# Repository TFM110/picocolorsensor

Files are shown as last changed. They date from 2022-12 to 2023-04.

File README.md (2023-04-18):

# REV Color Sensor Raspberry Pi Pico

This uses a Serial connection to transmit data for 2 Rev Color Sensors to a roboRIO using a Pi Pico.

## Pi Pico Setup

You can follow the raspberry pi instructions to build the executable in the pico folder. Their instructions are complicated for windows, so I have also provided a prebuilt uf2 file to directly upload to the device. To deploy this file this, hold down the button on your devide, and connect to your computer. This will open as a drive. Copy the picocolorsensor.uf2 file in the `pico` folder to the drive. It will automatically reboot and start running the code with no configuration required.

## Hardware connections

By default, the code will connect to 2 color sensors. 

Please solder all the necessary components onto the PCB, files are provided in the `Pico Color Sensor PCB` folder to print/order your own PCB as well as the Bill of Materials(BOM) needed for the PCB.

You may solder both the DuPont and/or the JST connector but you may only use one on both sides.

V2



Differences between V1 and V2:

* Replaced the SMDs with THTs components so teams don’t need to worry about small pieces and allows easier soldering with THTs
* Made the DuPont headers at a right angle to minimize the usage of the vertical space
* Both the Dupont and JST connector face the side
* FIXED: The JST connector on the V1 had the SDA and SCL channels in the wrong pins, V2 has fixed that. This allows you to use a regular 4-pin JST PH cable from the color sensor to the board. NOTE: When plugging the JST connector into the board, the connector must be upside down then how you plug into the color sensor.

V2.1



V2.5



Differences between V2 and V2.1/V2.5

* V2.1 and V2.5 now have 4 layers of traces instead of 2

Differences between V2.1 and V2.5

* V2.5 now has a male MXP port to allow you to use a NavX.
* V2.5 also has extra mounting holes for you to be able to securely mount the NavX
* NOTE: Due to the rule R713 in the 2022 Game Manual, you are not allowed to use any of the pins available on the NavX to control any actuators

## WPILib Setup

Copy the files corresponding to the language you use in the `wpilib` folder into your project. Instantiate a `PicoColorSensor` (java) or `pico::ColorSensor` (C++) object. You can only create 1 instance of this object. You can then use the functions to grab each color sensors value, and if its connected.

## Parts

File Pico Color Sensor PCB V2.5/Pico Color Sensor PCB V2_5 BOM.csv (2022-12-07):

Component Count: | 12
Ref | Qnty | Value | Cmp name | Footprint | Description | Vendor | Price | Total
Pico1, | 1 | Pico | Pico | MCU_RaspberryPi_and_Boards:RPi_Pico_SMD_TH | Raspberry Pi Pico | https://www.raspberrypi.com/products/raspberry-pi-pico/?variant=raspberry-pi-pico | $4.00 | $4.00
DuPont_I2C_1, DuPont_I2C_2, | 2 | Conn_01x04_Male | Conn_01x04_Male | Connector_PinHeader_2.54mm:PinHeader_1x04_P2.54mm_Horizontal | Generic connector, single row, 01x04 | https://www.digikey.com/en/products/detail/adam-tech/PH1RA-04-UA/9830430 | $0.19 | $0.38
JST_I2C_1, JST_I2C_2, | 2 | Conn_01x04_Male | Conn_01x04_Male | Connector_JST:JST_PH_S4B-PH-K_1x04_P2.00mm_Horizontal | Generic connector, single row, 01x04 | https://www.digikey.com/en/products/detail/jst-sales-america-inc/S4B-PH-K-S-LF-SN/926628 |  | $-
MXP1, | 1 | Conn_02x17_Odd_Even | Conn_02x17_Odd_Even | Connector_PinSocket_2.54mm:PinSocket_2x17_P2.54mm_Vertical | Generic connector, double row, 02x17, odd/even pin numbering scheme (row 1 odd numbers, row 2 even numbers) | https://www.digikey.com/en/products/detail/sullins-connector-solutions/SFH11-PBPC-D17-ST-BK/1990092 | $1.81 | $1.81
MXP2, | 1 | Conn_02x17_Odd_Even | Conn_02x17_Odd_Even | Connector_PinHeader_2.54mm:PinHeader_2x17_P2.54mm_Vertical | Generic connector, double row, 02x17, odd/even pin numbering scheme (row 1 odd numbers, row 2 even numbers) | https://www.digikey.com/en/products/detail/sullins-connector-solutions/SBH11-PBPC-D17-ST-BK/1990067 | $0.68 | $0.68
D1, | 1 | D | D | Diode_THT:D_DO-15_P10.16mm_Horizontal | Diode | https://www.digikey.com/en/products/detail/littelfuse-inc/SA5-0A/407714 | $0.43 | $0.43
R1, R2, R3, R4, | 4 | R | R | Resistor_THT:R_Axial_DIN0207_L6.3mm_D2.5mm_P10.16mm_Horizontal | Resistor | https://www.digikey.com/en/products/detail/stackpole-electronics-inc/CF14JT4K70/1741428 | $0.10 | $0.40
 |  |  |  |  |  |  |  | $7.70

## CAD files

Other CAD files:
KiCad-RP-Pico-main/SketchUp Model/Pico.skp

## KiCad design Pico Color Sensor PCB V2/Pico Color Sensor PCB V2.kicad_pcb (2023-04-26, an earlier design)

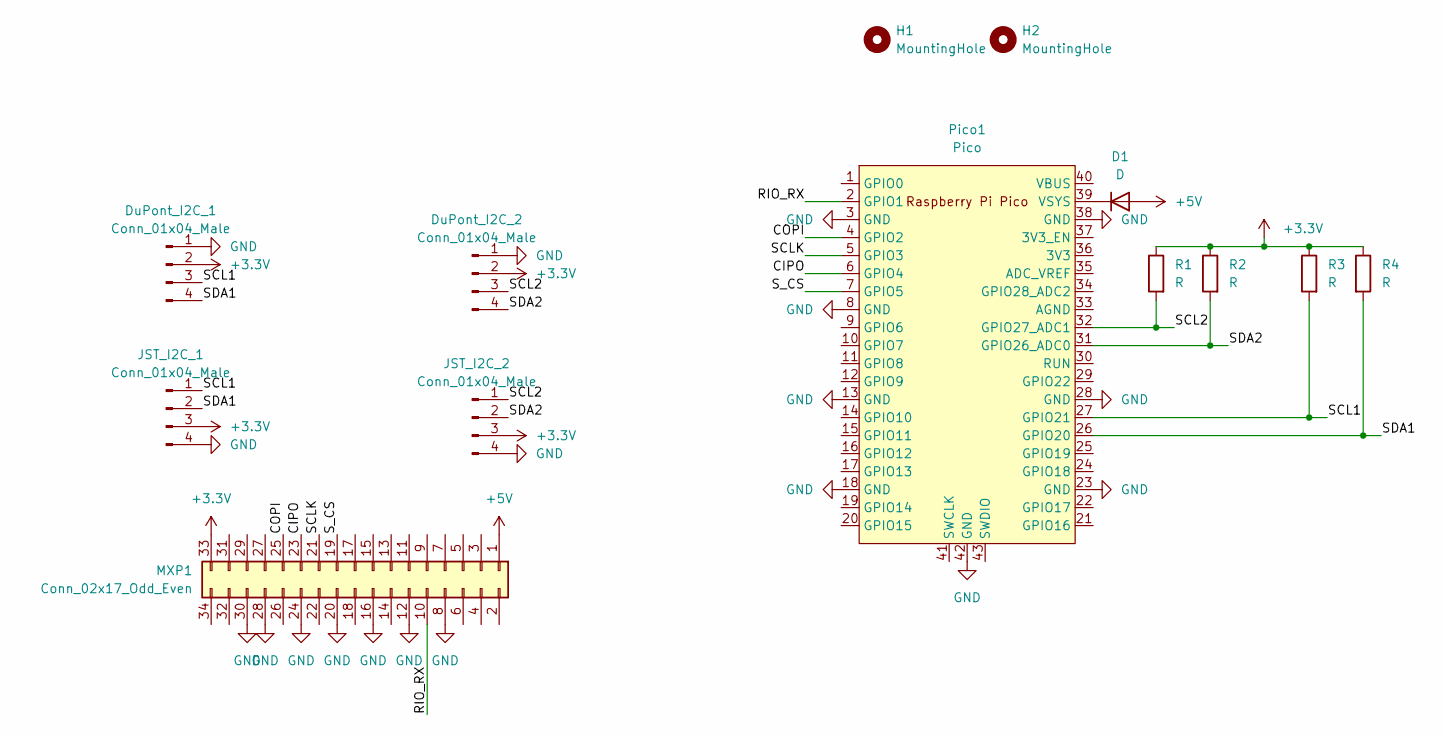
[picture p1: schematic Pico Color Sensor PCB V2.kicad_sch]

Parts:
D1: D; D_DO-15_P12.70mm_Horizontal
DuPont_I2C_1, DuPont_I2C_2: Conn_01x04_Male; PinHeader_1x04_P2.54mm_Horizontal
H1, H2: MountingHole; MountingHole_3.2mm_M3
JST_I2C_1, JST_I2C_2: Conn_01x04_Male; JST_PH_S4B-PH-K_1x04_P2.00mm_Horizontal
MXP1: Conn_02x17_Odd_Even; PinSocket_2x17_P2.54mm_Vertical
Pico1: Pico; RPi_Pico_SMD_TH
R1, R2, R3, R4: R; R_Axial_DIN0207_L6.3mm_D2.5mm_P10.16mm_Horizontal

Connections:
+3.3V: DuPont_I2C_1.2, DuPont_I2C_2.2, JST_I2C_1.3, JST_I2C_2.3, MXP1.33, R1.1, R2.1, R3.1, R4.1
+5V: D1.2 (A), MXP1.1
/CIPO: MXP1.23, Pico1.6 (GPIO4)
/COPI: MXP1.25, Pico1.4 (GPIO2)
/RIO_RX: MXP1.10, Pico1.2 (GPIO1)
/SCL1: DuPont_I2C_1.3, JST_I2C_1.1, Pico1.27 (GPIO21), R3.2
/SCL2: DuPont_I2C_2.3, JST_I2C_2.1, Pico1.32 (GPIO27_ADC1), R1.2
/SCLK: MXP1.21, Pico1.5 (GPIO3)
/SDA1: DuPont_I2C_1.4, JST_I2C_1.2, Pico1.26 (GPIO20), R4.2
/SDA2: DuPont_I2C_2.4, JST_I2C_2.2, Pico1.31 (GPIO26_ADC0), R2.2
/S_CS: MXP1.19, Pico1.7 (GPIO5)
GND: DuPont_I2C_1.1, DuPont_I2C_2.1, JST_I2C_1.4, JST_I2C_2.4, MXP1.8, MXP1.12, MXP1.16, MXP1.20, MXP1.24, MXP1.28, MXP1.30, Pico1.3 (GND), Pico1.8 (GND), Pico1.13 (GND), Pico1.18 (GND), Pico1.23 (GND), Pico1.28 (GND), Pico1.38 (GND), Pico1.42 (GND)
unnamed: D1.1 (K), Pico1.39 (VSYS)

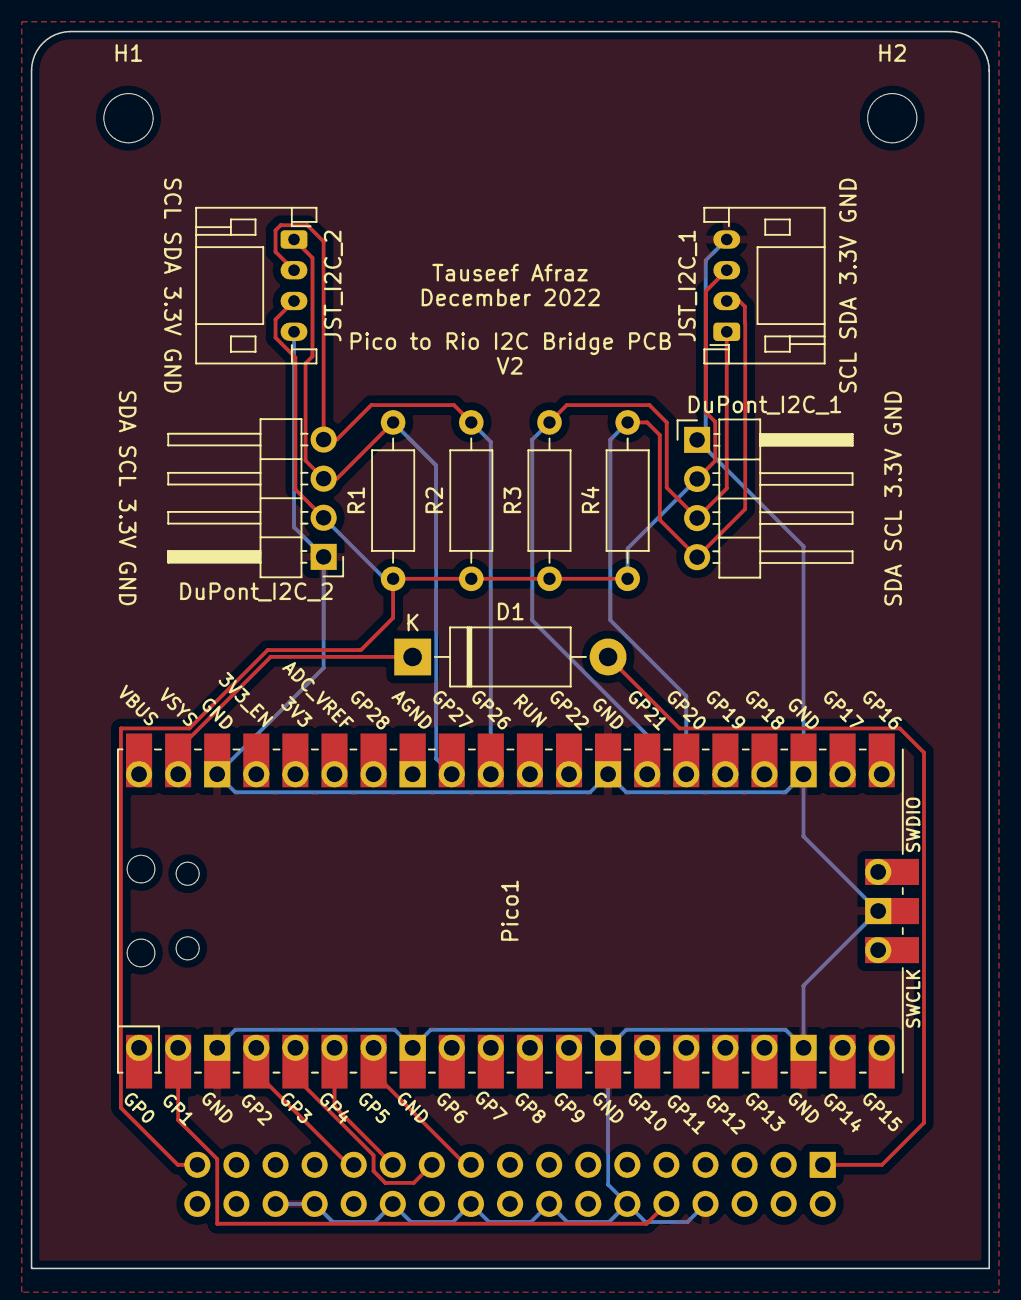
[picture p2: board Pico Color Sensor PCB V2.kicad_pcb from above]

Board: 2 copper layers, 62.2 x 80.4 mm, 13 parts (1 on the bottom side), 13 nets.

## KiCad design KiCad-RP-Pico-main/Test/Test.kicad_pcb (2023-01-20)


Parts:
J1, J2: Conn_01x20; PinSocket_1x20_P1.00mm_Vertical
J3: Conn_01x03; PinSocket_1x03_P1.00mm_Vertical
U1: Pico; RPi_Pico_SMD_TH

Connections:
GND: J1.3, J1.8, J1.13, J1.18, J2.3, J2.13, J2.18, J3.2, U1.3 (GND), U1.8 (GND), U1.13 (GND), U1.18 (GND), U1.23 (GND), U1.28 (GND), U1.38 (GND), U1.42 (GND)
unnamed: J1.1, U1.1 (GPIO0)
unnamed: J1.2, U1.2 (GPIO1)
unnamed: J1.4, U1.4 (GPIO2)
unnamed: J1.5, U1.5 (GPIO3)
unnamed: J1.6, U1.6 (GPIO4)
unnamed: J1.7, U1.7 (GPIO5)
unnamed: J1.9, U1.9 (GPIO6)
unnamed: J1.10, U1.10 (GPIO7)
unnamed: J1.11, U1.11 (GPIO8)
unnamed: J1.12, U1.12 (GPIO9)
unnamed: J1.14, U1.14 (GPIO10)
unnamed: J1.15, U1.15 (GPIO11)
unnamed: J1.16, U1.16 (GPIO12)
unnamed: J1.17, U1.17 (GPIO13)
unnamed: J1.19, U1.19 (GPIO14)
unnamed: J1.20, U1.20 (GPIO15)
unnamed: J2.1, U1.40 (VBUS)
unnamed: J2.2, U1.39 (VSYS)
unnamed: J2.4, U1.37 (3V3_EN)
unnamed: J2.5, U1.36 (3V3)
unnamed: J2.6, U1.35 (ADC_VREF)
unnamed: J2.7, U1.34 (GPIO28_ADC2)
unnamed: J2.8, U1.33 (AGND)
unnamed: J2.9, U1.32 (GPIO27_ADC1)
unnamed: J2.10, U1.31 (GPIO26_ADC0)
unnamed: J2.11, U1.30 (RUN)
unnamed: J2.12, U1.29 (GPIO22)
unnamed: J2.14, U1.27 (GPIO21)
unnamed: J2.15, U1.26 (GPIO20)
unnamed: J2.16, U1.25 (GPIO19)
unnamed: J2.17, U1.24 (GPIO18)
unnamed: J2.19, U1.22 (GPIO17)
unnamed: J2.20, U1.21 (GPIO16)
unnamed: J3.1, U1.43 (SWDIO)
unnamed: J3.3, U1.41 (SWCLK)


Board: 2 copper layers, 43.0 x 65.0 mm, 4 parts (0 on the bottom side), 36 nets.

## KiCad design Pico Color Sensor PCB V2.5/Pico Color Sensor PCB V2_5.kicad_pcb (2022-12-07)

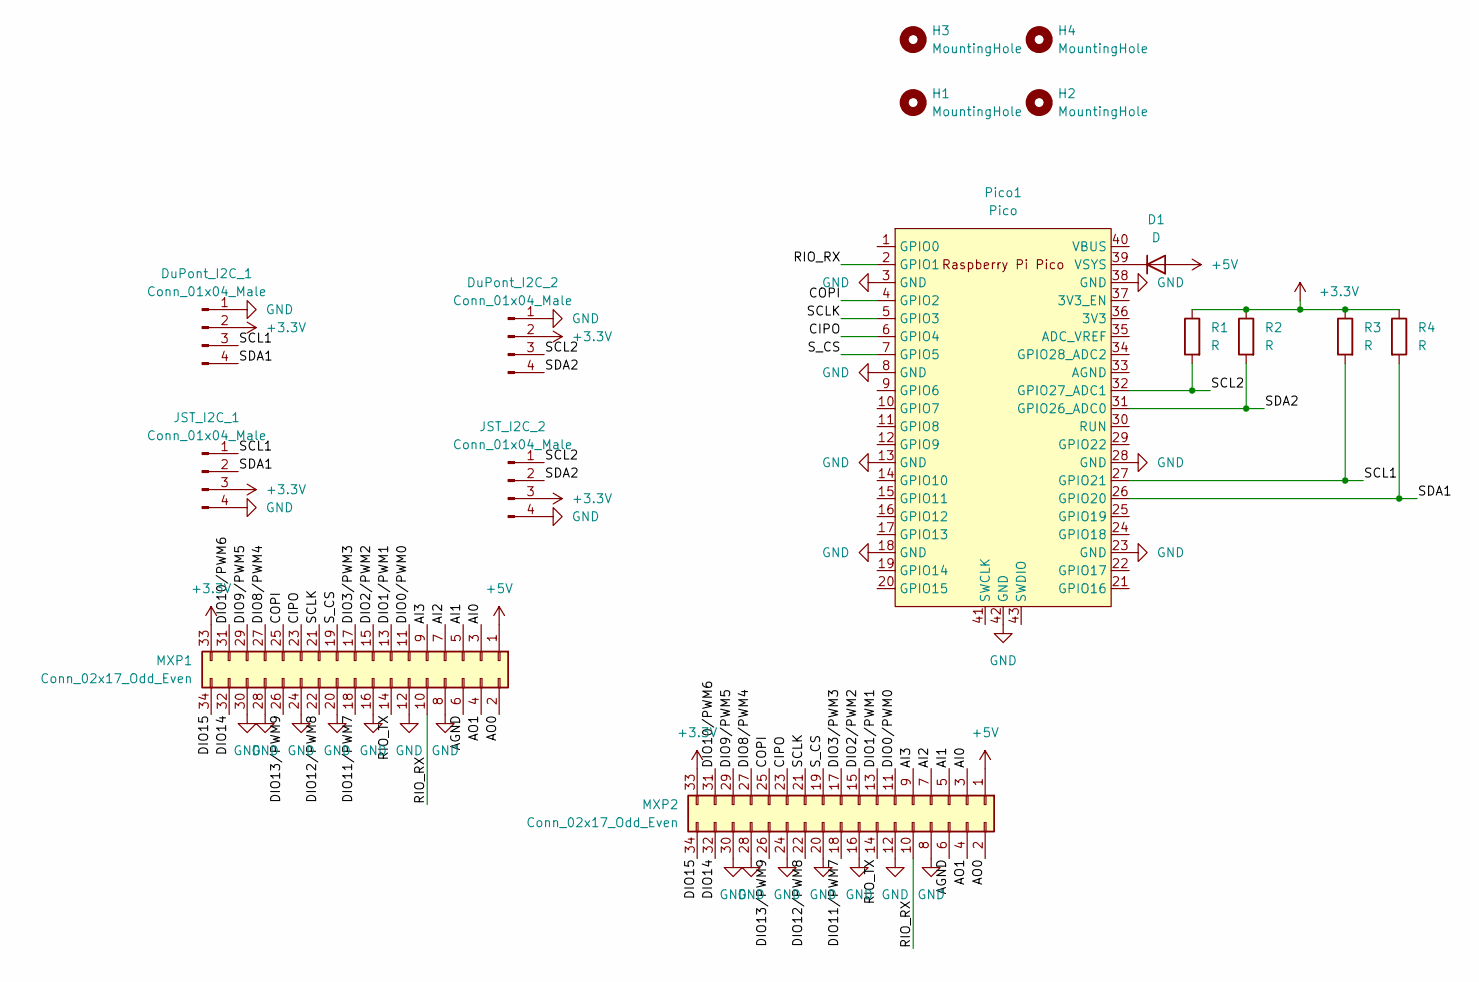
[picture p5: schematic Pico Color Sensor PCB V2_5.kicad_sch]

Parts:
D1: D; D_DO-15_P12.70mm_Horizontal
DuPont_I2C_1, DuPont_I2C_2: Conn_01x04_Male; PinHeader_1x04_P2.54mm_Horizontal
H1, H2, H3, H4: MountingHole; MountingHole_3.2mm_M3
JST_I2C_1, JST_I2C_2: Conn_01x04_Male; JST_PH_S4B-PH-K_1x04_P2.00mm_Horizontal
MXP1: Conn_02x17_Odd_Even; PinSocket_2x17_P2.54mm_Vertical
MXP2: Conn_02x17_Odd_Even; PinHeader_2x17_P2.54mm_Vertical
Pico1: Pico; RPi_Pico_SMD_TH
R1, R2, R3, R4: R; R_Axial_DIN0207_L6.3mm_D2.5mm_P10.16mm_Horizontal

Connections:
+3.3V: DuPont_I2C_1.2, DuPont_I2C_2.2, JST_I2C_1.3, JST_I2C_2.3, MXP1.33, MXP2.33, R1.1, R2.1, R3.1, R4.1
+5V: D1.2 (A), MXP1.1, MXP2.1
/AGND: MXP1.6, MXP2.6
/AI0: MXP1.3, MXP2.3
/AI1: MXP1.5, MXP2.5
/AI2: MXP1.7, MXP2.7
/AI3: MXP1.9, MXP2.9
/AO0: MXP1.2, MXP2.2
/AO1: MXP1.4, MXP2.4
/CIPO: MXP1.23, MXP2.23, Pico1.6 (GPIO4)
/COPI: MXP1.25, MXP2.25, Pico1.4 (GPIO2)
/DIO0/PWM0: MXP1.11, MXP2.11
/DIO1/PWM1: MXP1.13, MXP2.13
/DIO2/PWM2: MXP1.15, MXP2.15
/DIO3/PWM3: MXP1.17, MXP2.17
/DIO8/PWM4: MXP1.27, MXP2.27
/DIO9/PWM5: MXP1.29, MXP2.29
/DIO10/PWM6: MXP1.31, MXP2.31
/DIO11/PWM7: MXP1.18, MXP2.18
/DIO12/PWM8: MXP1.22, MXP2.22
/DIO13/PWM9: MXP1.26, MXP2.26
/DIO14: MXP1.32, MXP2.32
/DIO15: MXP1.34, MXP2.34
/RIO_RX: MXP1.10, MXP2.10, Pico1.2 (GPIO1)
/RIO_TX: MXP1.14, MXP2.14
/SCL1: DuPont_I2C_1.3, JST_I2C_1.1, Pico1.27 (GPIO21), R3.2
/SCL2: DuPont_I2C_2.3, JST_I2C_2.1, Pico1.32 (GPIO27_ADC1), R1.2
/SCLK: MXP1.21, MXP2.21, Pico1.5 (GPIO3)
/SDA1: DuPont_I2C_1.4, JST_I2C_1.2, Pico1.26 (GPIO20), R4.2
/SDA2: DuPont_I2C_2.4, JST_I2C_2.2, Pico1.31 (GPIO26_ADC0), R2.2
/S_CS: MXP1.19, MXP2.19, Pico1.7 (GPIO5)
GND: DuPont_I2C_1.1, DuPont_I2C_2.1, JST_I2C_1.4, JST_I2C_2.4, MXP1.8, MXP1.12, MXP1.16, MXP1.20, MXP1.24, MXP1.28, MXP1.30, MXP2.8, MXP2.12, MXP2.16, MXP2.20, MXP2.24, MXP2.28, MXP2.30, Pico1.3 (GND), Pico1.8 (GND), Pico1.13 (GND), Pico1.18 (GND), Pico1.23 (GND), Pico1.28 (GND), Pico1.38 (GND), Pico1.42 (GND)
unnamed: D1.1 (K), Pico1.39 (VSYS)

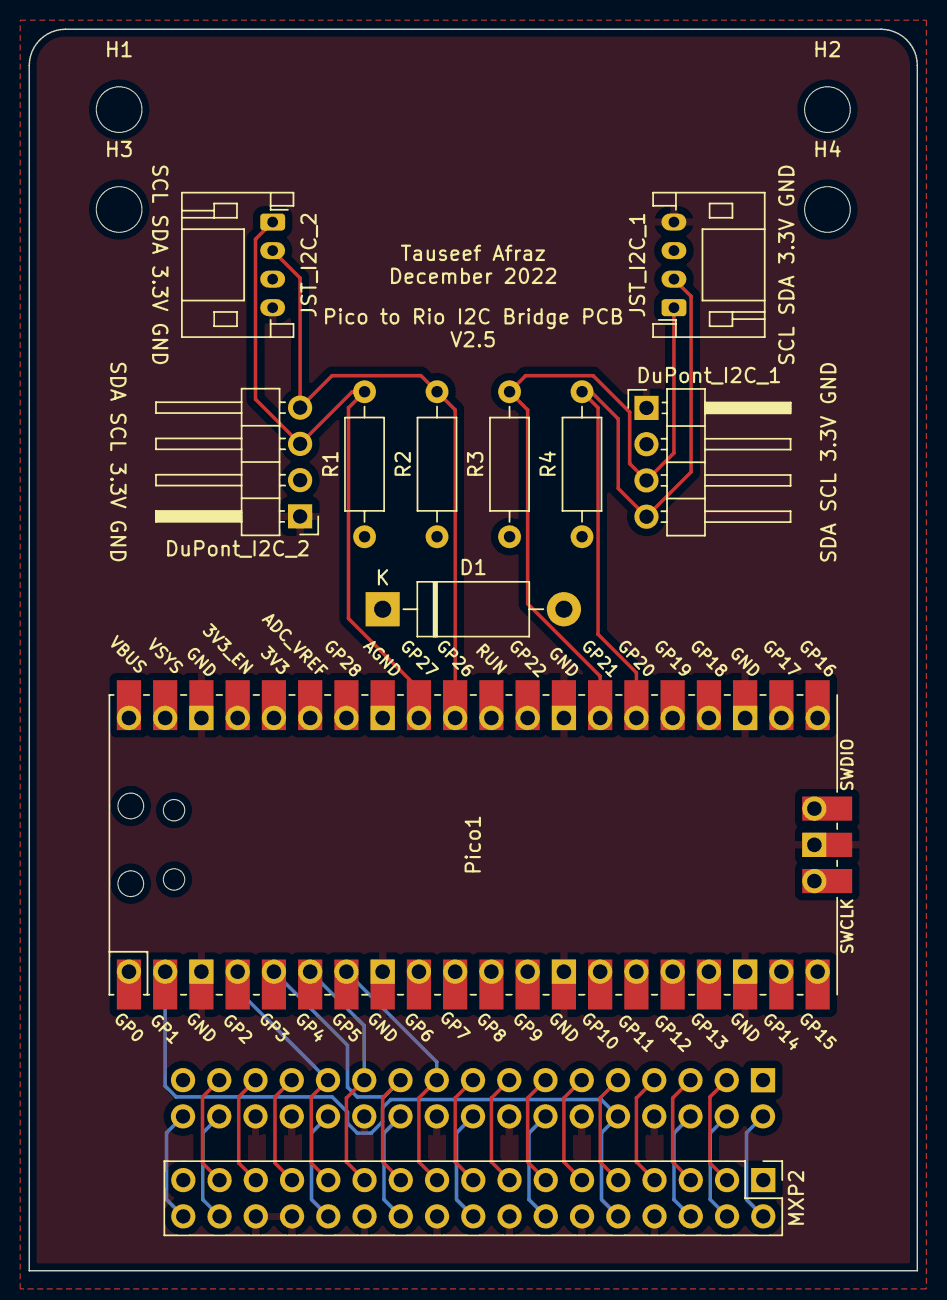
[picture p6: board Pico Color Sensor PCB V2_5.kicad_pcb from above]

Board: 4 copper layers, 62.2 x 87.0 mm, 16 parts (1 on the bottom side), 33 nets.

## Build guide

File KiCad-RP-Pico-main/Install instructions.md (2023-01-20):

# Install instructions

## 1. Copy the files locally

Copy the `RP-Pico Libraries` folder wherever you like on your computer.

## 2. Install the Raspberry Pi Pico board schema symbol

Use the `KiCad | Preferences | Manage Symbol Libraries...` command to manage the symbol library:



then select the global tab and click on the folder button:



navigate to the `RP-Pico Libraries` folder, select the `MCU_RaspberryPi_and_Boards.kicad_sym` file and open it:



et voilà, the first step is completed:



You can now close the symbol libraries manager window.

## 3. Install the Raspberry Pi Pico board footprint

You can use a similar approach to add the footprint to the footprint libraries manager, but I've found some issues that I've solved using the footprint editor, so here are the steps I suggest you to follow:

Open the footprint editor



wait for the footprints to load... then use the `File | Add Library` command:



confirm the `Global` choice:



and select the `MCU_RaspberriPi_and_Boards.pretty` folder (yes, the folder represent a footprint library on KiCad):



Now the library is installed on KiCad with the Raspberry Pi Pico footprint (double click on it to see it on the editor pane):



Don't close the windows as the next step start from here.

## 4. Install the Raspberry Pi Pico board footprint 3D visual

If not already open, open the the footprint editor

symbol library manager

double click on the `RPi_Pico_SMD_TH` footprint from the `MCU_RaspberriPi_and_Boards` library and then click on the `Footprint properties` icon:



In the footprint properties window, first select the `3D Settings` tab. Please note that the preview shows only the PCB board with the footprint added on step 3, without any 3D representation of the Raspberry Pi Pico board. Now click on the folder icon to add the 3D model:



Navigate to the `RP-Pico Libraries` folder, select the `Pico.wrl` file and wait until the model is shown in the right panel, then confirm with OK:



The model is already scaled and translated to match the footprint:



now close the `Footprint Properties` window, and the `Footprint Editor`, obviously saving the changes.

## Conclusion

Now that you've installed the schema and footprint and added the 3D model to the footprint, you can use the Raspberry Pi Pico board on your KiCad projects.

I've also added a test KiCad Project on the `Test` folder, that you can use to see an example of it.

Have fun!

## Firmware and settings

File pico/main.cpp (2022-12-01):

#include <stdio.h>
#include <string.h>
#include <stdlib.h>
#include "pico/stdlib.h"
#include "hardware/uart.h"
#include "hardware/i2c.h"
#include "pico/binary_info.h"

enum class GainFactor
{
    k1x = 0,
    k3x = 1,
    k6x = 2,
    k9x = 3,
    k18x = 4
};

enum class LEDPulseFrequency
{
    k60kHz = 0x18,
    k70kHz = 0x40,
    k80kHz = 0x28,
    k90kHz = 0x30,
    k100kHz = 0x38,
};

enum class LEDCurrent
{
    kPulse2mA = 0,
    kPulse5mA = 1,
    kPulse10mA = 2,
    kPulse25mA = 3,
    kPulse50mA = 4,
    kPulse75mA = 5,
    kPulse100mA = 6,
    kPulse125mA = 7,
};

enum class ProximityResolution
{
    k8bit = 0x00,
    k9bit = 0x08,
    k10bit = 0x10,
    k11bit = 0x18,
};

enum class ProximityMeasurementRate
{
    k6ms = 1,
    k12ms = 2,
    k25ms = 3,
    k50ms = 4,
    k100ms = 5,
    k200ms = 6,
    k400ms = 7,
};

enum class ColorResolution
{
    k20bit = 0x00,
    k19bit = 0x10,
    k18bit = 0x20,
    k17bit = 0x30,
    k16bit = 0x40,
    k13bit = 0x50,
};

enum class ColorMeasurementRate
{
    k25ms = 0,
    k50ms = 1,
    k100ms = 2,
    k200ms = 3,
    k500ms = 4,
    k1000ms = 5,
    k2000ms = 7,
};

enum class Register
{
    kMainCtrl = 0x00,
    kProximitySensorLED = 0x01,
    kProximitySensorPulses = 0x02,
    kProximitySensorRate = 0x03,
    kLightSensorMeasurementRate = 0x04,
    kLightSensorGain = 0x05,
    kPartID = 0x06,
    kMainStatus = 0x07,
    kProximityData = 0x08,
    kDataInfrared = 0x0A,
    kDataGreen = 0x0D,
    kDataBlue = 0x10,
    kDataRed = 0x13
};

enum class MainCtrlFields
{
    kProximitySensorEnable = 0x01,
    kLightSensorEnable = 0x02,
    kRGBMode = 0x04
};

static constexpr int kAddress = 0x52;
static constexpr int kExpectedPartID = 0xC2;
// static constexpr GainFactor kDefaultGain =
//     GainFactor::k3x;
// static constexpr LEDPulseFrequency kDefaultPulseFreq =
//     LEDPulseFrequency::k60kHz;
// static constexpr LEDCurrent kDefaultLEDCurrent =
//     LEDCurrent::kPulse100mA;
// static constexpr uint8_t kDefaultPulses = 32;
// static constexpr ProximityResolution kDefaultProxRes =
//     ProximityResolution::k11bit;
// static constexpr ProximityMeasurementRate kDefaultProxRate =
//     ProximityMeasurementRate::k50ms;
// static constexpr ColorResolution kDefaultColorRes =
//     ColorResolution::k18bit;
// static constexpr ColorMeasurementRate kDefaultColorRate =
//     ColorMeasurementRate::k100ms;

bool read_i2c_data(i2c_inst_t *i2c, Register reg, uint8_t *buffer, uint8_t readLen)
{
    buffer[0] = static_cast<uint8_t>(reg);
    int result = i2c_write_timeout_us(i2c, kAddress, buffer, 1, true, 25000);
    if (result != 1)
    {
        return false;
    }
    result = i2c_read_timeout_us(i2c, kAddress, buffer, readLen, false, 25000);
    return result == readLen;
}

void init_device(i2c_inst_t *i2c, uint8_t *i2cBuffer)
{
    i2cBuffer[0] = static_cast<uint8_t>(Register::kMainCtrl);
    i2cBuffer[1] = static_cast<uint8_t>(MainCtrlFields::kRGBMode) |
                   static_cast<uint8_t>(MainCtrlFields::kLightSensorEnable) |
                   static_cast<uint8_t>(MainCtrlFields::kProximitySensorEnable);
    i2c_write_timeout_us(i2c, kAddress, i2cBuffer, 2, false, 25000);

    i2cBuffer[0] = static_cast<uint8_t>(Register::kProximitySensorRate);
    i2cBuffer[1] = static_cast<uint8_t>(ProximityResolution::k11bit) | static_cast<uint8_t>(ProximityMeasurementRate::k100ms);
    i2c_write_timeout_us(i2c, kAddress, i2cBuffer, 2, false, 25000);

    i2cBuffer[0] = static_cast<uint8_t>(Register::kProximitySensorPulses);
    i2cBuffer[1] = 32;
    i2c_write_timeout_us(i2c, kAddress, i2cBuffer, 2, false, 25000);

    // i2cBuffer[0] = static_cast<uint8_t>(Register::kLightSensorMeasurementRate);
    // i2cBuffer[1] = static_cast<uint8_t>(kDefaultColorRes) | static_cast<uint8_t>(kDefaultColorRate);
    // i2c_write_timeout_us(i2c, kAddress, i2cBuffer, 2, false, 25000);

    // i2cBuffer[0] = static_cast<uint8_t>(Register::kLightSensorGain);
    // i2cBuffer[1] = static_cast<uint8_t>(kDefaultGain);
    // i2c_write_timeout_us(i2c, kAddress, i2cBuffer, 2, false, 25000);
}

int main()
{
    // Init uart
    uart_init(uart0, 115200);
    gpio_set_function(PICO_DEFAULT_UART_TX_PIN, GPIO_FUNC_UART);
    gpio_set_function(PICO_DEFAULT_UART_RX_PIN, GPIO_FUNC_UART);

    // Init I2c 0
    i2c_init(i2c0, 400000);
    gpio_set_function(20, GPIO_FUNC_I2C);
    gpio_set_function(21, GPIO_FUNC_I2C);
    gpio_pull_up(20);
    gpio_pull_up(21);

    // Init I2c 1
    i2c_init(i2c1, 400000);
    gpio_set_function(26, GPIO_FUNC_I2C);
    gpio_set_function(27, GPIO_FUNC_I2C);
    gpio_pull_up(26);
    gpio_pull_up(27);

    // Channel 0 output
    gpio_init(14);
    gpio_set_dir(14, GPIO_OUT);
    gpio_put(14, 1);

    // Channel 1 output
    gpio_init(15);
    gpio_set_dir(15, GPIO_OUT);
    gpio_put(15, 1);

    char outputBuffer[512];

    unsigned int values[10];
    uint8_t i2cBuffer[20];
    bool currentValid0 = false;
    bool currentValid1 = false;
    absolute_time_t loopTime;
    bool reset;

    sleep_ms(100);

    init_device(i2c0, i2cBuffer);
    read_i2c_data(i2c0, Register::kMainStatus, i2cBuffer, 1);

    init_device(i2c1, i2cBuffer);
    read_i2c_data(i2c1, Register::kMainStatus, i2cBuffer, 1);

    memset(values, 0, sizeof(values));

    while (1)
    {
        loopTime = make_timeout_time_ms(100);

        currentValid0 = read_i2c_data(i2c0, Register::kMainStatus, i2cBuffer, 15);
        if (currentValid0)
        {
            if ((i2cBuffer[0] & 0x20) != 0)
            {
                init_device(i2c0, i2cBuffer);
            }
            else
            {
                values[4] = ((i2cBuffer[1] & 0xFF) | ((i2cBuffer[2] & 0xFF) << 8)) & 0x7FF;
                values[3] = ((i2cBuffer[3] & 0xFF) | ((i2cBuffer[4] & 0xFF) << 8) | ((i2cBuffer[5] & 0xFF) << 16)) & 0x03FFFF;
                values[2] = ((i2cBuffer[6] & 0xFF) | ((i2cBuffer[7] & 0xFF) << 8) | ((i2cBuffer[8] & 0xFF) << 16)) & 0x03FFFF;
                values[1] = ((i2cBuffer[9] & 0xFF) | ((i2cBuffer[10] & 0xFF) << 8) | ((i2cBuffer[11] & 0xFF) << 16)) & 0x03FFFF;
                values[0] = ((i2cBuffer[12] & 0xFF) | ((i2cBuffer[13] & 0xFF) << 8) | ((i2cBuffer[14] & 0xFF) << 16)) & 0x03FFFF;
            }
        }

        currentValid1 = read_i2c_data(i2c1, Register::kMainStatus, i2cBuffer, 15);
        if (currentValid1)
        {
            if ((i2cBuffer[0] & 0x20) != 0)
            {
                init_device(i2c1, i2cBuffer);
            }
            else
            {
                values[9] = ((i2cBuffer[1] & 0xFF) | ((i2cBuffer[2] & 0xFF) << 8)) & 0x7FF;
                values[8] = ((i2cBuffer[3] & 0xFF) | ((i2cBuffer[4] & 0xFF) << 8) | ((i2cBuffer[5] & 0xFF) << 16)) & 0x03FFFF;
                values[7] = ((i2cBuffer[6] & 0xFF) | ((i2cBuffer[7] & 0xFF) << 8) | ((i2cBuffer[8] & 0xFF) << 16)) & 0x03FFFF;
                values[6] = ((i2cBuffer[9] & 0xFF) | ((i2cBuffer[10] & 0xFF) << 8) | ((i2cBuffer[11] & 0xFF) << 16)) & 0x03FFFF;
                values[5] = ((i2cBuffer[12] & 0xFF) | ((i2cBuffer[13] & 0xFF) << 8) | ((i2cBuffer[14] & 0xFF) << 16)) & 0x03FFFF;
            }
        }

        snprintf(outputBuffer, sizeof(outputBuffer), "%u,%u,%u,%u,%u,%u,%u,%u,%u,%u,%u,%u\n",
                 currentValid0, currentValid1, values[0], values[1], values[2], values[3], values[4], values[5], values[6], values[7], values[8], values[9]);

        uart_puts(uart0, outputBuffer);

        sleep_until(loopTime);
    }
}

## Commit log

2022-11-29 Added pcb files. WIP
    [Pico Color Sensor.kicad_pcb, Pico Color Sensor.kicad_sch]
2022-12-01 Updating PCB. Code still needs to be worked on
    [Pico Color Sensor PCB BOM.csv, Pico Color Sensor PCB.kicad_pcb, Pico Color Sensor PCB.kicad_sch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]
2022-12-01 Added the gerber files
2022-12-01 fingers crossed, this is the new uf2
2022-12-01 updated BOM with current prices
    [Pico Color Sensor PCB BOM.csv]
2022-12-01 Updated pinouts for JST
    [Pico Color Sensor PCB.kicad_pcb, Pico Color Sensor PCB.kicad_sch]
2022-12-05 Updated text
    [Pico Color Sensor PCB.kicad_pcb]
2022-12-06 Added V2 Text
    [Pico Color Sensor PCB.kicad_pcb]
2022-12-07 Added V2.1 and V2.5
    [Pico Color Sensor PCB BOM.csv, Pico Color Sensor PCB V2 BOM.csv, Pico Color Sensor PCB V2.kicad_pcb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]
2022-12-07 Made V2.5 board a bit longer
    [Pico Color Sensor PCB V2_5.kicad_pcb]
2022-12-07 Updated V2.1 and V2.5 BOM sheets title
    [Pico Color Sensor PCB V2_1 BOM.csv, Pico Color Sensor PCB V2_5 BOM.csv]
2023-01-20 add pico files to repo
    [Pico.skp, Test.kicad_pcb, Test.kicad_sch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]
2023-04-26 i did changes i guess
    [Pico Color Sensor PCB V2.kicad_pcb]
